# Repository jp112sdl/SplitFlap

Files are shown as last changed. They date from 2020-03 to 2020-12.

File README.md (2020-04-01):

# DIY Split-Flap Display - Work In Progress!

### SplitFlap Display based on the [scottbez1/splitflap](https://github.com/scottbez1/splitflap) project

Modifications:
- **45 flaps** :  ` `, `A-Z`, `0-9`, `Ä`, `Ö`, `Ü`, `ß`, `,` , `.`, `!`, `?` _(40 flaps on the original)_
- laser-cuttable [propylen cover sheets](https://www.ebay.de/itm/390361527869) as flaps
- uses the ULN2003 driver delivered with the [28byj-48 stepper motors](https://www.amazon.de/gp/product/B07VGV1XFT)
- controlling **12 displays with one single [Mega2560 PRO MINI](https://de.aliexpress.com/item/32966042485.html) board** _(no custom pcb necessary)_
  - _next step will be an [Arduino Mega2560 with WiFi](https://de.aliexpress.com/item/33011577070.html) board_
- use [A3144 hall sensors](https://www.ebay.de/itm/182592276084)



### construction site pictures ^^ 
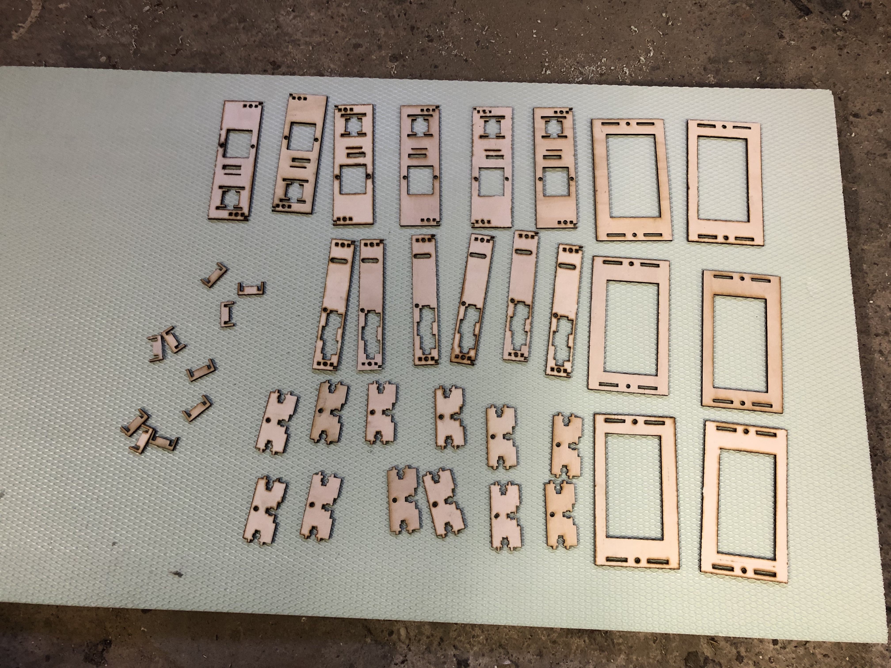
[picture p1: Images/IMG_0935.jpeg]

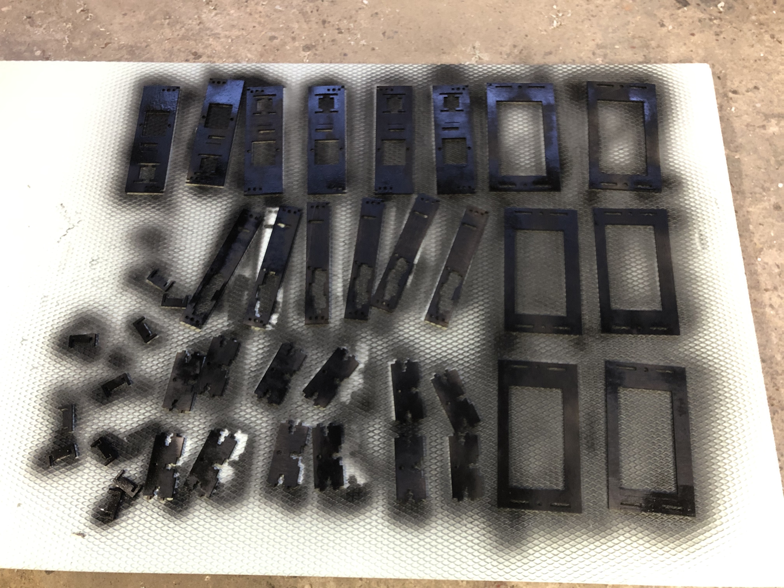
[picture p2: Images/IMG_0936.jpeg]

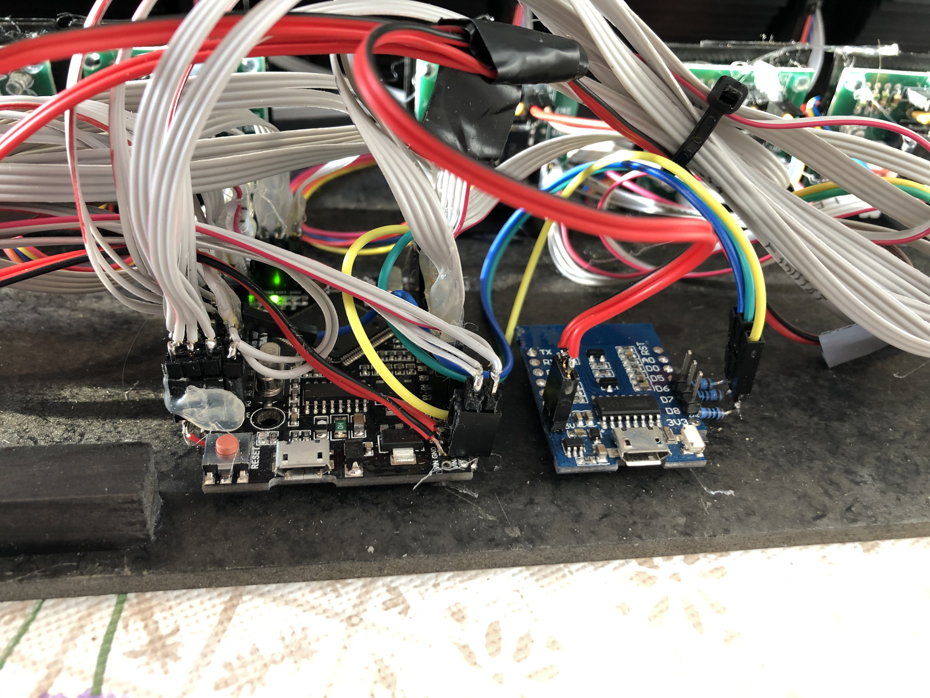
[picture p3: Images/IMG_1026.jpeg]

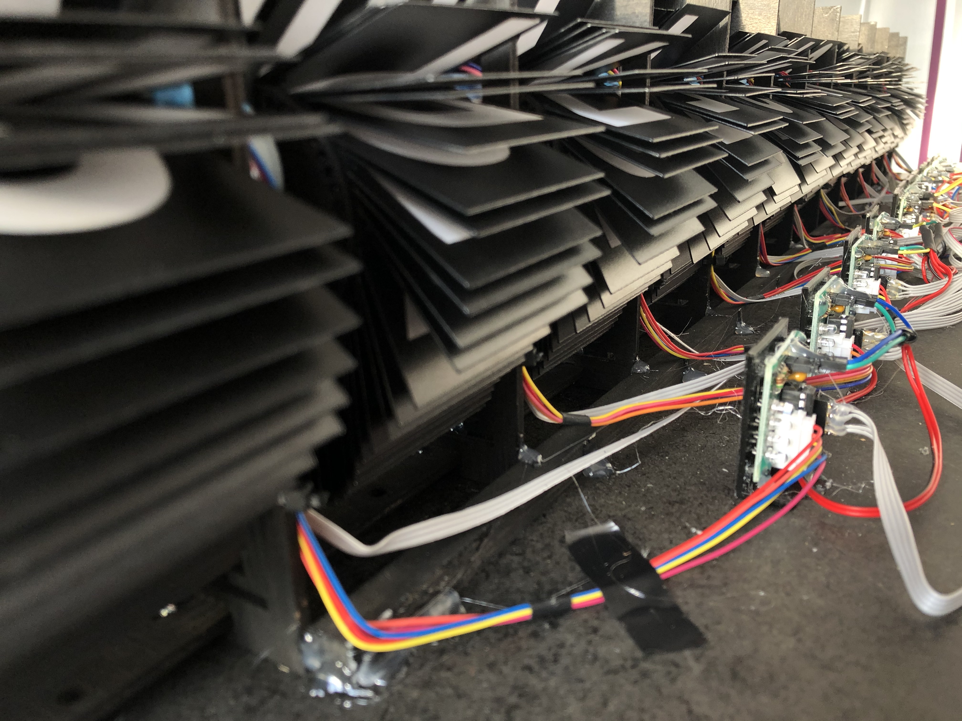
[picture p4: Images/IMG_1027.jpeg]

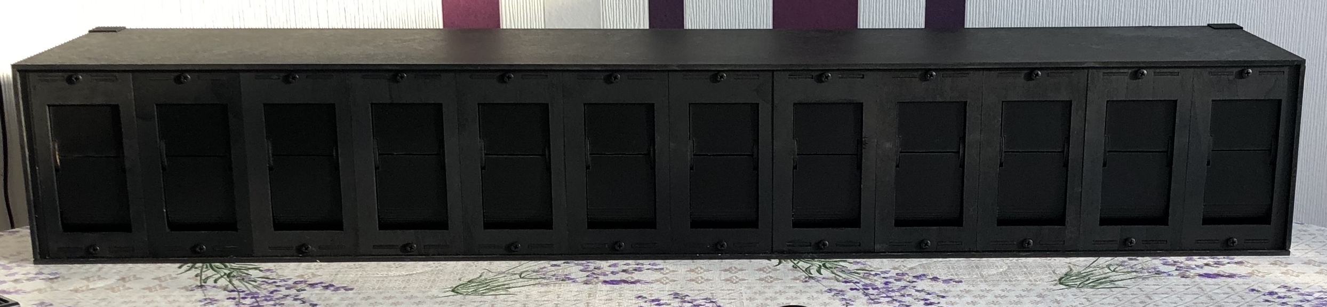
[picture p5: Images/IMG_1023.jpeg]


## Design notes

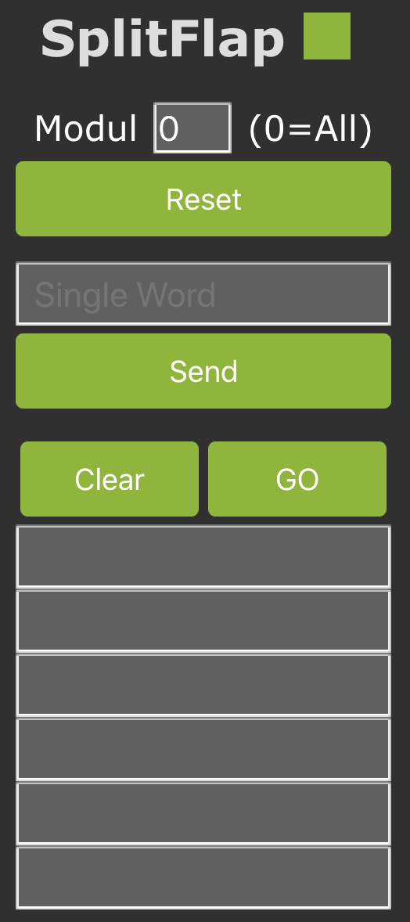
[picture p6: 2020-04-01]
Images/web.png

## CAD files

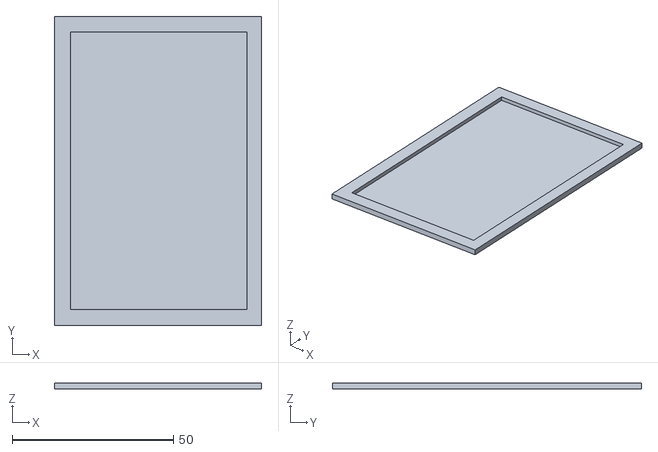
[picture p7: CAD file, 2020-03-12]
FlapHolderFrame.stl
64.2 x 95.8 x 2.00

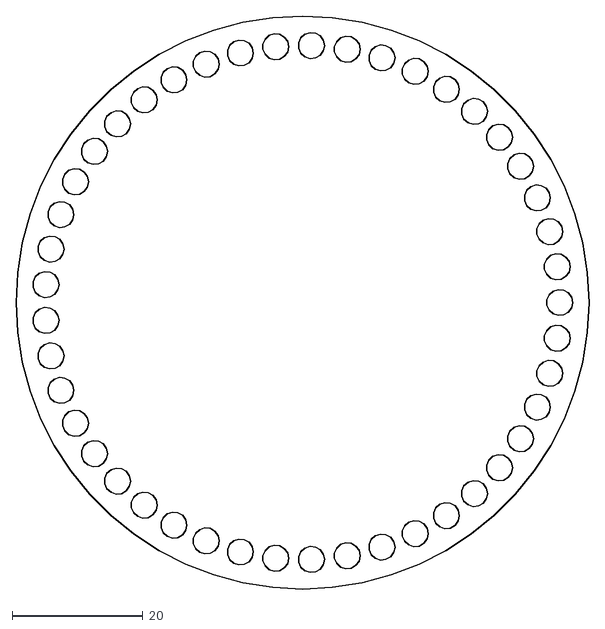
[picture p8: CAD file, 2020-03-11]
spool45.dxf
87.8 x 87.8

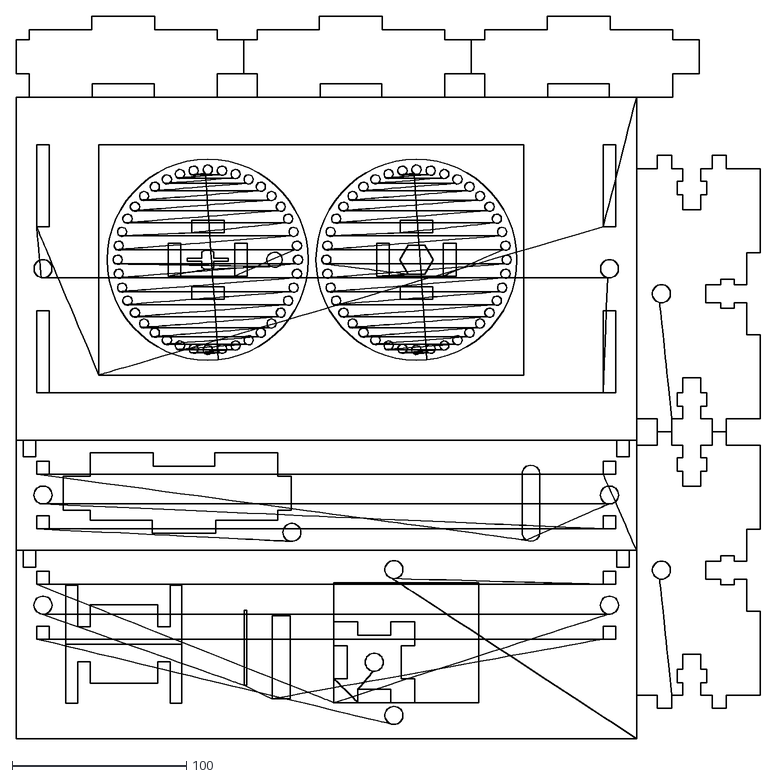
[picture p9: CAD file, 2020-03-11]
3d_laser_vector.dxf
427.5 x 414.9

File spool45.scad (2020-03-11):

/*
   Copyright 2015-2016 Scott Bezek and the splitflap contributors

   Licensed under the Apache License, Version 2.0 (the "License");
   you may not use this file except in compliance with the License.
   You may obtain a copy of the License at

       http://www.apache.org/licenses/LICENSE-2.0

   Unless required by applicable law or agreed to in writing, software
   distributed under the License is distributed on an "AS IS" BASIS,
   WITHOUT WARRANTIES OR CONDITIONS OF ANY KIND, either express or implied.
   See the License for the specific language governing permissions and
   limitations under the License.
*/

module flap_spool(flaps, flap_hole_radius, flap_gap, outset, height) {
    pitch_radius = flap_spool_pitch_radius(flaps, flap_hole_radius, flap_gap);
    outer_radius = flap_spool_outer_radius(flaps, flap_hole_radius, flap_gap, outset);


    module flap_spool_2d() {
        difference() {
            circle(r=outer_radius, $fn=60);
            for (i = [0 : flaps - 1]) {
                translate([cos(360/flaps*i)*pitch_radius, sin(360/flaps*i)*pitch_radius]) circle(r=flap_hole_radius, $fn=15);
            }
        }
    }

    if (height > 0) {
        linear_extrude(height) {
            flap_spool_2d();
        }
    } else {
        flap_spool_2d();
    }

}

function flap_spool_pitch_radius(flaps, flap_hole_radius, separation) = 
    flaps * (flap_hole_radius*2 + separation) / (2*PI);

function flap_spool_outer_radius(flaps, flap_hole_radius, separation, outset) = 
    flap_spool_pitch_radius(flaps, flap_hole_radius, separation) + flap_hole_radius + outset;

  flap_spool(45, 2, 1.5, 2.5, 0);
//flap_spool(40, 2,     2, 3, 0);

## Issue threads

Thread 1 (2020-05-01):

Letters on Flaps?

mattkerrison, 2020-05-01:
Hey!

Just wondering how you're getting the letters on the polypropylene flaps? Are you applying the sticker packs that Scott Bezek uses, or are you printing onto the sheets before cutting them?

jp112sdl, 2020-05-12:
I used self-adhesive labels (i.e. https://www.labelident.com/eb105x148ppwe.html)
The letters were cut with the laser cutter out of that labels.
4 letters fit on 1 sheet.
I put them in groups of 4 letters in SVG files here:https://github.com/jp112sdl/SplitFlap/tree/master/Letters

Closed 2021-01-04.

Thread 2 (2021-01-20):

Slit Flap strange Behaviour

daniele8808, 2021-01-20:
Hello Jerome, I saw your project and it's seem working very well. I've also tried to make my display using the ScottBez1 file but I'm having some problem displaying the correct character inside my module. I wrote to Scott but maybe it's to busy to help me so I'm wondering if you had the same problems I'm having and if you can help me to solve is.
I have completed the construction of a module and mechanically it should be ok, I have also done some tests with the sensor and it is correctly detected but I still cannot see the letter I want on my display. In this short video I show the three problems I'm having:

https://youtu.be/BHOUhOT_epA (this video was made for Scott but explain which are my problems)

1 error: often when I select a letter to view the display freezes after 2 steps for no reason
2 error: if I try to display a character that is too far from the starting point (for example I switch from A to Z), the display makes a complete revolution and returns to A, but no errors are reported on the console
3 error: a few times when I recalibrate by entering the @ the display arrives at the home point and adds a micro step that changes the initial letter

I would be really grateful if you could help me complete this project.
Thanks in advance

Daniele

jp112sdl, 2021-04-01:
Hi and sorry for the late reply.

It's been a long time ago since working on my splitflap so... I hope I can help you

1.) Can be a bad power supply?

2+3) Are you using my code from here: https://github.com/jp112sdl/SplitFlap/blob/master/Code/SplitFlap/SplitFlap.ino ?

I have declared an offset `ZERO_OFFSET_DEFAULTS`:
https://github.com/jp112sdl/SplitFlap/blob/a9b46231fd3726ffb9cbe177fb51e2d02c6dcdb5/Code/SplitFlap/SplitFlap.ino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

The position, where the magnet reaches the hall sensor, is nearly on the **last** flap.
Then I added some steps (`ZERO_OFFSET_DEFAULTS`) that let the last flap falll to the the first flap.

daniele8808, 2021-04-01:
Hello Jerome,
Thanks for the answer, I still managed to solve my problem by doing some debugging. The problem was with the cards not moving well and for this reason the engine was trying too hard and I was unable to display the letters I wanted. However, I thank you anyway for your availability.

Daniele

Closed 2021-04-17.

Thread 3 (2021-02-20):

doubt in the code of esp8266

carlos-rener, 2021-02-20:
hi congratulations for the project, I set up 4 modules I am a programming student, I want to understand the code of esp8266, not being able to understand where you connected the engine wires and how you send the words to the split flap? thanks.

jp112sdl, 2021-04-01:
Hi,
sorry for the late reply.

The Mega2560, where all steppers are connected, uses `Serial2` (Pins 16 and 17) and the Esp8266, providing the web interface, uses a software serial on `D6` and `D7`
https://github.com/jp112sdl/SplitFlap/blob/a9b46231fd3726ffb9cbe177fb51e2d02c6dcdb5/Code/SplitFlap_ESP8266/SplitFlap_ESP8266.ino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

Everytime you see a `splitflapSerial.print(...)` in the code, a command is sent to the Mega2560.
Especially for displaying text, there is a small stack that can be filled with texts and a wait time between displaying the text
https://github.com/jp112sdl/SplitFlap/blob/master/Code/SplitFlap_ESP8266/SplitFlap_ESP8266.ino#L23-L26

Then, the text is sent within the `loop()`
https://github.com/jp112sdl/SplitFlap/blob/master/Code/SplitFlap_ESP8266/SplitFlap_ESP8266.ino#L597-L612

Closed 2021-08-05.

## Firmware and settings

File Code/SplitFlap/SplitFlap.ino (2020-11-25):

#include <AccelStepper.h>
#include "avr/eeprom.h"

#define BUSY_LED                 A9
#define STEPPER_COUNT            12
#define NUM_FLAPS                45
#define STEPS_PER_ROUND          4096
#define STEPS_PER_FLAP           (STEPS_PER_ROUND * 1.0 / NUM_FLAPS * 1.0)
#define ACCELERATION             10000.0
float   SPEED              =     1000.0;

#define EEPROM_ZERO_OFFSET_START 128

const uint8_t SENSOR_PINS[STEPPER_COUNT] = {  A0 ,  A2  ,  A4 ,  A6 ,  A8  , A10 , A12 , A14 , A1  , A3 ,  A5,  A7 };
const uint8_t ZERO_OFFSET_DEFAULTS[STEPPER_COUNT] = { 110 ,  100 ,  115 , 170 , 190 , 110 , 120 , 190 , 165 , 95 , 130,  80 };

AccelStepper steppers[STEPPER_COUNT] = {
  AccelStepper(AccelStepper::HALF4WIRE,   4,  3,  2,  5),
  AccelStepper(AccelStepper::HALF4WIRE,   8,  7,  6,  9),
  AccelStepper(AccelStepper::HALF4WIRE,  12, 11, 10, 13),
  AccelStepper(AccelStepper::HALF4WIRE,  20, 19, 18, 21),
  AccelStepper(AccelStepper::HALF4WIRE,  24, 23, 22, 25),
  AccelStepper(AccelStepper::HALF4WIRE,  28, 27, 26, 29),
  AccelStepper(AccelStepper::HALF4WIRE,  42, 41, 40, 43), 
  AccelStepper(AccelStepper::HALF4WIRE,  46, 45, 44, 47),
  AccelStepper(AccelStepper::HALF4WIRE,  38, 37, 36, 39),
  AccelStepper(AccelStepper::HALF4WIRE,  34, 33, 32, 35),
  AccelStepper(AccelStepper::HALF4WIRE,  30, 52, 31, 53),
  AccelStepper(AccelStepper::HALF4WIRE,  50, 49, 48, 51)
};

bool running[STEPPER_COUNT] = {0, 0, 0, 0, 0, 0, 0, 0, 0, 0, 0, 0};
uint8_t ZERO_OFFSET[STEPPER_COUNT];

String serialInput = "";
//                                                     ÄÖÜ ß
String letters = " ABCDEFGHIJKLMNOPQRSTUVWXYZ0123456789[](-)!?.";

unsigned long lastmillis = 0;
uint8_t       cnt = 0;

void initHW() {
  Serial.println("initHW()");
  if (eeprom_read_byte(0) != 0xaa) {
    Serial.print(F("EEPROM Byte 0 != 0xAA => writing ZERO_OFFSET_DEFAULTS to EEPROM... "));
    eeprom_write_byte(0, 0xaa);
    eeprom_write_block((const void*)&ZERO_OFFSET_DEFAULTS, (void*)EEPROM_ZERO_OFFSET_START, STEPPER_COUNT);
    Serial.println(" done");
  }
  eeprom_read_block((void*)&ZERO_OFFSET, (void*)EEPROM_ZERO_OFFSET_START, STEPPER_COUNT);
  Serial.print(F("Zero Offsets: { "));
  for (uint8_t i = 0; i < STEPPER_COUNT; i++) {
    Serial.print(ZERO_OFFSET[i], DEC);
    if (i < STEPPER_COUNT-1) Serial.print(", ");
  }
  Serial.println(" }");

  for (uint8_t j = 0; j < STEPPER_COUNT; j++) {
    steppers[j].setMaxSpeed(SPEED);
    steppers[j].setAcceleration(ACCELERATION);
    steppers[j].setSpeed(SPEED);
    pinMode(SENSOR_PINS[j], INPUT_PULLUP);
  }
  pinMode(BUSY_LED, OUTPUT);
}

void setBusyLED(bool s) {
  digitalWrite(BUSY_LED, s);
}

void gotoZero(uint8_t moduleNum) {
  setBusyLED(true);

  Serial.print("gotoZero("); Serial.print(moduleNum);Serial.print(")");
  steppers[moduleNum].enableOutputs();
  steppers[moduleNum].setSpeed(SPEED);
  bool zeroPos = (digitalRead(SENSOR_PINS[moduleNum]) == 0);
  while (zeroPos) {
    zeroPos = (digitalRead(SENSOR_PINS[moduleNum]) == 0);
    steppers[moduleNum].runSpeed();
  }
  unsigned long zeroPosStartMillis = millis();
  uint16_t timeout = (1000 / SPEED) * 4500;
  Serial.print(" timeout=");Serial.print(timeout,DEC);
  while (!zeroPos && millis() - zeroPosStartMillis < timeout) {
    zeroPos = (digitalRead(SENSOR_PINS[moduleNum]) == 0);
    if (zeroPos) {
      unsigned long zduration = millis()-zeroPosStartMillis;
      Serial.print("  Zero Pos detected (");Serial.print(zduration, DEC);Serial.println("ms)");
      steppers[moduleNum].setCurrentPosition(0);
      steppers[moduleNum].runToNewPosition(ZERO_OFFSET[moduleNum]);
    }
    steppers[moduleNum].runSpeed();
  }
  if (!zeroPos) {
    Serial.println(" TIMEOUT!");
    Serial2.print("T");Serial2.print(moduleNum, DEC);Serial2.print("\n");
  }
  steppers[moduleNum].setCurrentPosition(0);
  //Serial.print("setCurrentPosition(0) : ("); Serial.print(moduleNum); Serial.print(","), Serial.print(disable); Serial.println(")");
  steppers[moduleNum].disableOutputs();
  setBusyLED(false);
}

void setZeroPosOffset(uint8_t moduleNum, uint16_t val) {
  ZERO_OFFSET[moduleNum] = val;
  eeprom_write_block((const void*)&ZERO_OFFSET, (void*)EEPROM_ZERO_OFFSET_START, STEPPER_COUNT);
  Serial.print("New ZERO POS for Module ");Serial.print(moduleNum, DEC);Serial.print(" set to "); Serial.print(val, DEC); Serial.println(" and written to EEPROM");
}

void gotoZeroAll() {
  for (uint8_t j = 0; j < STEPPER_COUNT; j++) {
    gotoZero(j);
  }
  Serial.println("gotoZeroAll -> Finish!");
}

void gotoLetter(char printletter, uint8_t moduleNum) {
  Serial.print("gotoLetter("); Serial.print(printletter); Serial.print(","); Serial.print(moduleNum); Serial.println(")");

  uint16_t stepsFromZero = 0;

  for (uint8_t i = 0; i < letters.length(); i++) {
    if (letters[i] == printletter) {
      break;
    }
    stepsFromZero += STEPS_PER_FLAP;
  }

  uint16_t currentPosition = steppers[moduleNum].currentPosition();

  uint16_t steps = (stepsFromZero > currentPosition) ? stepsFromZero - currentPosition : (STEPS_PER_ROUND - currentPosition) + stepsFromZero;

  if (steps != STEPS_PER_ROUND) steppers[moduleNum].move(steps);
}

bool processFlapRun() {
  bool isBusy = false;
  for (uint8_t j = 0; j < STEPPER_COUNT; j++) {
    if (steppers[j].distanceToGo() != 0 && !running[j]) {
      //Serial.print("Enable  Steppers ("); Serial.print(j, DEC); Serial.println(")");
      steppers[j].enableOutputs();
      running[j] = true;
    }

    steppers[j].run();

    if (steppers[j].distanceToGo() == 0 && running[j]) {
      //Serial.print("Disable Steppers ("); Serial.print(j, DEC); Serial.println(")");
      if (steppers[j].currentPosition() > STEPS_PER_ROUND) {
        steppers[j].setCurrentPosition(steppers[j].currentPosition() - STEPS_PER_ROUND);
      }
      steppers[j].disableOutputs();
      running[j] = false;
    }

    if (running[j]) lastmillis = millis();
    if (running[j]) isBusy = true;
  }
  return isBusy;
}

void setup() {
  Serial.begin(57600);
  Serial2.begin(19200);
  initHW();
}

void loop() {
  bool busy = processFlapRun();

  setBusyLED(busy);

  bool newChar = false;
  if (!busy && (Serial.available() > 0 || Serial2.available() > 0)) {
    char in = (Serial.available() > 0) ? Serial.read() : Serial2.read();
    if (in == '\n') {
      newChar = true;
    } else {
      serialInput += in;
    }
  }

  if (newChar) {
    newChar = false;

    if (serialInput[0] == '%') {
      switch (serialInput[1]) {

      case 'z': {
        if (serialInput[2] == 'a') {
          gotoZeroAll();
        } else {
          int modnum = atoi(serialInput.substring(2).c_str());
          gotoZero(modnum);
        }
      }
        break;

      case 'o': {
        int modnum = atoi(serialInput.substring(2,4).c_str());
        uint16_t val = constrain(atoi(serialInput.substring(4).c_str()), 0, 4096);
        setZeroPosOffset(modnum, val);
        //gotoZero(modnum);
      }
        break;

      case 's': {
        uint16_t s = constrain(atoi(serialInput.substring(2).c_str()), 100, 1000);
        SPEED = s * 1.0;
        initHW();
        Serial.print("Setting SPEED to ");Serial.println(SPEED, DEC);
      }
        break;


      case 'g': {
        String s = "{\"SPEED\":";
        s += String((uint16_t)SPEED, DEC);
        s += ",\"ZERO_OFFSET\": [";
        for (uint8_t i = 0; i < STEPPER_COUNT; i++) {
          s+= String(ZERO_OFFSET[i], DEC);
          if (i < STEPPER_COUNT-1) s+=(", ");
        }
        s+="]}\n";

        Serial.print(s);
        Serial2.print(s);
      }
        break;

      }
    }

    if (serialInput.length() == (STEPPER_COUNT)) {
      serialInput.toUpperCase();
      for (uint8_t i = 0; i < STEPPER_COUNT; i++) {
        char letter = serialInput[i];
        gotoLetter(letter, i);
      }
    }
    serialInput = "";
  }
}

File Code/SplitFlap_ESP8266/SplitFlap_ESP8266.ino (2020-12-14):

#include <ESP8266WiFi.h>
#include <ESP8266WebServer.h>
#include <ESP8266HTTPUpdateServer.h>
#include <ESP8266mDNS.h>
#include <SoftwareSerial.h>
#include <ArduinoJson.h>
#include <ArduinoOTA.h>
#include "secrets.h"

#define BUSY_PIN      D5
#define NUM_MODULES   12

ESP8266WebServer server(80);
ESP8266HTTPUpdateServer httpUpdater;
SoftwareSerial splitflapSerial(D7, D6);

String lasttext = "";
String serialInput = "";

const char * host = "SPLITFLAP";
bool blocked = false;

struct {
  String msg;
  int wait;
} SplitFlapCommand[64];

uint8_t msgcnt = 0;
uint8_t msgidx = 0;
unsigned long stopMillis = 0;
uint16_t waitMillisBetween  = 2000;
bool OTAStart = false;

const char HEAD[] PROGMEM = R"=====(
  <head>
    <meta name="viewport" content="width=device-width, initial-scale=1, user-scalable=no" />
    <meta http-equiv="Content-Type" content="text/html; charset=utf-8" />
    <meta name="apple-mobile-web-app-capable" content="yes">
    <title>SplitFlap</title>
    <style>
      body{
        text-align: center;
        font-family:verdana;
        background-color: #303030;
        color: white;
        font-size:1.4rem; 
        padding: 10px;
      } 
  
      input.lnkbtnred,input.lnkbtngn,input.lnkbtnback ,button{
        border:0;
        border-radius:0.3rem;
        color:#fff;
        line-height:2.4rem;
        font-size:1.2rem;
        width:240px;
        padding: 5px 10px;
        margin-top: 5px;
      } 

      button {
        background-color: #83b817;
      }

      input.lnkbtnback {
        background-color: #1fa3ec;
        padding: 5px 10px;
        margin-bottom: 5px;
        width:114px;
      }

      input.lnkbtnred {
        background-color: #ff6666;
      } 
      
      .listbtn {
        width:114px;
        padding: 5px 10px;
        margin-bottom: 5px;
      }

      .savebtn {
        width:114px;
        padding: 5px 10px;
        margin-bottom: 5px;
        background-color: #ff6666;
      }

      input.lnkbtnred,input.lnkbtngn,.savebtn {
        -webkit-appearance: button;
        -moz-appearance: button;
        appearance: button;
      } 
      
      label {
        color: white;
        font-size:1.4rem; 
        padding: 10px;
      }

      table {
         margin: 0 auto;
      }
      
      td.name {
       text-align: right;
       font-size:1.4rem;
      }

      #headline {
        display:flex;
        align-items:center;
        justify-content: center;
       }
  
      .flap-state {
        width: 30px;
        height: 30px;
        background-color: #83b817;
        display: inline-block;
        border: 1px solid #303030;
        margin: 5px 10px;
      }

      .flap-state__busy {
        background-color: red;
        animation: flipping 1.5s linear infinite;
      }

      .flap-state__unknown {
        background-color: yellow;
      }

      input[name=text] {
        width: 240px;
        max-width: 90vw;
        background-color: #606060;
        color: white;
        padding: 5px 5px;
        font-size:1.4rem;
      }
      
      .num {
        background-color: #606060;
        color: white;
        font-size:1.4rem;
        padding: 5px 5px;
      }

      .waittime {
        width: 55px;
      }
      
      .reset {
        width: 65px;
      }

      .offset {
        width: 80px;
        text-align:left;
      }

      input[type=submit] {
        margin-top: 5px;
        padding: 5px 10px;
      }

     form {
        margin-bottom: 0em;
      }

      @keyframes flipping {
        from {
          transform: rotateX(0deg);
        }

        to {
          transform: rotateX(360deg);
        }
      }
    </style>
  </head>
)=====";

const char CONFIG_page[] PROGMEM = R"=====(
<html>
  {head}
  <body>
    <div class="center">
      <form action="/config" method="post">
      <div><table>
        {offset_lines}
      </table></div>
        <div><button  class='savebtn' type="submit">Save</button>
      <input class='lnkbtnback' type='button' value='Back' onclick="window.location.href='/'" /></div> 
      </form>
    </div>
  </body>
</html>
)=====";

const char MAIN_page[] PROGMEM = R"=====(
<html>
  {head}
  <body>
    <h1 style="color:#ddd;" id="headline">
      SplitFlap
      <span class="flap-state flap-state__unkown" id="state"></span>
    </h1>

    <div class="center">
      <form action="/" method="post">
        <div><label for="reset_module">Modul</label><input class="num reset" id="reset_module" type="number" name="reset" value="0" min="0" max="{num_modules}"><label>(0=All)</label></div>
        <div><button>Reset</button></div>
      </form>
      
      <form action="/" method="post" id="frm">
        <div><input id="textfield" type="text" maxlength={num_modules} onfocus="this.value=''" name="text" value="" placeholder="Single Word"></div>
        <div><input type="checkbox" id="center" name="center" checked><label for="center">zentriert</label></div>
        <div><button type="submit">Send</button></div>   
      </form>
      
      <form>
        <div>
          <button class="listbtn" type="button" onclick="ClearBtn()">Clear</button>
          <button class="listbtn" type="button" onclick="GoBtn();">GO</button>
        </div>
        <div><input id="textline1" type="text" maxlength={num_modules} onfocus="this.value=''" name="text" value="{t1}" placeholder="{t1}">&nbsp;<input class="num waittime" id="waitline1" type="number" name="waitline" value="{w1}" min="1" max="60">s</div>
        <div><input id="textline2" type="text" maxlength={num_modules} onfocus="this.value=''" name="text" value="{t2}" placeholder="{t2}">&nbsp;<input class="num waittime" id="waitline2" type="number" name="waitline" value="{w2}" min="1" max="60">s</div>
        <div><input id="textline3" type="text" maxlength={num_modules} onfocus="this.value=''" name="text" value="{t3}" placeholder="{t3}">&nbsp;<input class="num waittime" id="waitline3" type="number" name="waitline" value="{w3}" min="1" max="60">s</div>
        <div><input id="textline4" type="text" maxlength={num_modules} onfocus="this.value=''" name="text" value="{t4}" placeholder="{t4}">&nbsp;<input class="num waittime" id="waitline4" type="number" name="waitline" value="{w4}" min="1" max="60">s</div>
        <div><input id="textline5" type="text" maxlength={num_modules} onfocus="this.value=''" name="text" value="{t5}" placeholder="{t5}">&nbsp;<input class="num waittime" id="waitline5" type="number" name="waitline" value="{w5}" min="1" max="60">s</div>
        <div><input id="textline6" type="text" maxlength={num_modules} onfocus="this.value=''" name="text" value="{t6}" placeholder="{t6}">&nbsp;<input class="num waittime" id="waitline6" type="number" name="waitline" value="{w6}" min="1" max="60">s</div>
      </form>
      <div>
        <input class='lnkbtnred' type='button' value='Konfiguration' onclick="window.location.href='/config'" />
      </div>
    </div>
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

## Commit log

2020-03-11 add spool45.scad
    [spool45.scad]
2020-03-12 add FlapHolderFrame
    [FlapHolderFrame.stl]
2020-03-16 add stepper test sketch
2020-03-19 update laser parameters
2020-03-26 fix cut rate
2020-04-01 update calibration data
